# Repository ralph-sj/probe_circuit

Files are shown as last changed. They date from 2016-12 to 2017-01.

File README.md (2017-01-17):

# README
## RAS-J 12/01/2017

## Introduction
Here the design of a POF sensor is presented for the remote monitoring of a distillation column for use in undergraduate labs within Chemical Engineering.

## Hardware layout
The circuit is based around the LT1920 instrumentation amplifier which is used to amplify the signal from a photodiode with an incorporated trans-impedance amplifier.  

- Power input: this is supplied from a 12V supply connected to a 2.5mm jack on the front panel 
- LED power output: voltage for the LED's is connected to 2 banana plugs (red and black) on the front panel.
- Vsig output: this is the output signal and is connected by a BNC plug
- Vpd: the input from the photodiode.  This is at present connected via a 2.5mm audio jack but this can be replaced with a BNC connector

Resistors are used to set the levels for the offset voltage and the gain of the amplifier.  Switches are used to switch between variable resistors and fixed value resistors.  This is to enable the optimum level of both to be found and then set for future use.

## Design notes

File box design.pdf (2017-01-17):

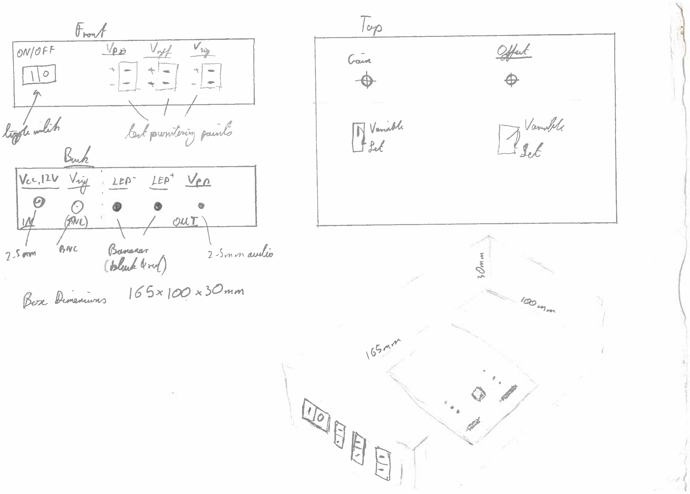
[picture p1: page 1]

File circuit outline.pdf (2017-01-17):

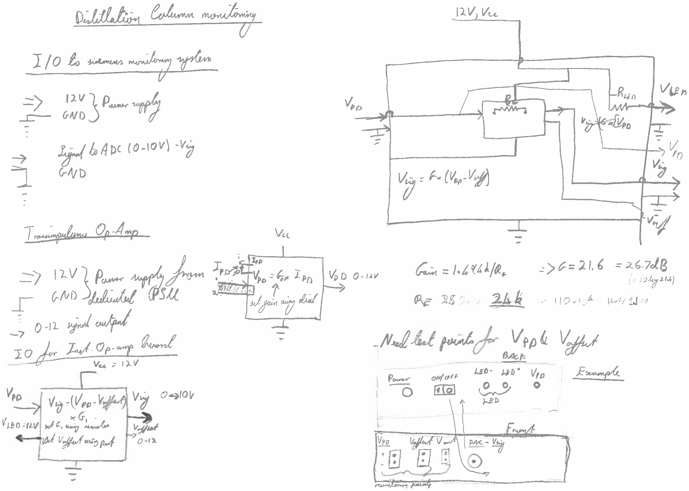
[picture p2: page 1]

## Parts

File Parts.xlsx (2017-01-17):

Distillation column BOM | RAS-J | 2016-10-28
Part | type | more info | size | purpose | No. required | Price | supplier link | Supplier order code | Mnfctr | Mnfctr. part no. | Net cost | Note
banana connector | plug | black | 4mm |  | 1 | £0.50 | farnel (http://uk.farnell.com/multicomp/24-247-2/receptacle-32a-4mm-panel-black/dp/1698951) | 1698951 | Multicomp | 24.247.2 | £0.50
banana connector | plug | red | 4mm |  | 1 | £0.50 | farnel (http://uk.farnell.com/multicomp/24-247-1/receptacle-32a-4mm-panel-red/dp/1698950) | 1698950 | Multicomp | 24.247.1 | £0.50
banana connector | jack | black | 4mm |  | 1 | £1.35 | farnel (http://uk.farnell.com/multicomp/25-413-2/plug-24a-4mm-cable-black/dp/1698964) | 1698964 | Multicomp | 25.413.2 | £1.35
banana connector | jack | red | 4mm |  | 1 | £1.35 | farnel (http://uk.farnell.com/multicomp/25-413-1/banana-plug-24a-4mm-cable-red/dp/1698963) | 1698963 | Multicomp | 25.413.1 | £1.35
DC power connector | plug | cable mount | 2.5mm |  | 1 | £0.50 | farnel (http://uk.farnell.com/multicomp/mp-122m/plug-dc-power-2-5mm/dp/1737249) | 1737249 | Multicomp | MP-122M | £0.50 | not needed if power supply used
DC power connector | jack | panel mount | 2.5mm |  | 1 | £0.90 | farnel (http://uk.farnell.com/multicomp/mj-15sr/chassis-socket-psu-panel-mount/dp/1737252) | 1737252 | Multicomp | MJ-15SR | £0.90
2-pole audio connector | plug | cable mount | 2.5mm |  | 1 | £0.73 | farnel (http://uk.farnell.com/lumberg/kls-2/connector-plug-3-5mm-mono-cable/dp/1243261) | 1243261 | Lumberg | KLS 2 | £0.73
2-pole audio connector | jack | panel mount | 2.5mm |  | 1 | £1.24 | farnel (http://uk.farnell.com/lumberg/kls-2/connector-plug-3-5mm-mono-cable/dp/1267394) | 1267394 | Pro Signal | MJ-164H | £1.24
DC power supply | mains AC adaptor | 12V, 10W output | 2.5mm jack |  | 1 | £7.50 | farnel (http://uk.farnell.com/multicomp/mcplg12v10wuk/plug-power-supply-10w-uk-12v/dp/1827445) | 1827445 | Multicomp | MCPLG12V10WUK | £7.50
On-off (rocker) switch | SPST | 250V, 16A max, illuminated |  |  | 1 | £1.16 | farnel (http://uk.farnell.com/multicomp/mc34231-091-72/rocker-switch-spst-red-i-o/dp/1454386) | 1454386 | Multicomp | MC34231-091-72 | £1.16
On-off (rocker) switch | SPST | 20A, non-illuminated, black/red |  |  | 1 | £0.64 | farnel (http://uk.farnell.com/multicomp/mc34224-071-1501/switch-spst-20a-250vac-blk-red/dp/1454382) | 1454382 | Multicomp | MC34224-071-1501 | £0.64
Potentiometer | Rotor | 10k, 200mW, +-20% |  | RG | 0 | £0.61 | farnel (http://uk.farnell.com/bi-technologies-tt-electronics/p160knp-0qc20b10k/pot-rotary-10k-20mm-20/dp/1760793) | 1760793 | BI Technologies | P160KNP-0QC20B10K | £0.00 | this or 249BBHS0XB25103KA
Potentiometer | Rotor | 10k, 1W, +-10% |  | RG | 1 | £6.94 | farnel (http://uk.farnell.com/vishay/249bbhs0xb25103ka/potentiometer-10k/dp/9609245?ost=249BBHS0XB25103KA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) | 9609245 | Vishay | 249BBHS0XB25103KA | £6.94 | this or P160KNP-0QC20B10K
BNC panel mount | jack | brass, <11GHz | 50 Ohm |  | 1 | £1.67 | farnel (http://uk.farnell.com/multicomp/13-25/rf-coaxial-bnc-straight-jack-50ohm/dp/1169699) | 1169699 | Multicomp | 13-25 | £1.67
Test point | thru-hole | for panel mounting | 1mm diameter |  | 1 | £1.41 | farnel (http://uk.farnell.com/multicomp/test-3/test-pin-pcb-1mm/dp/1702006) | 1702006 | Multicomp | TEST-3 | £1.41 | pack of 100, alt. to 1035
Test point | thru-hole | for panel mounting |  |  | 0 | £13.70 | farnel (http://uk.farnell.com/keystone/1035/test-point-pcb-through-hole/dp/2112492) | 2112492 | Keystone | 1035 | £0.00 | pack of 100, alt. to TEST-3
Potentiometer | thru-hole | 5k, 1W, +-10% |  | V_offset | 1 | £6.33 | farnel (http://uk.farnell.com/vishay/249bbhs0xb25502ka/potentiometer-5k/dp/9609237) | 9609237 | Vishay | 249BBHS0XB25502KA | £6.33
Switch | SPDT | panel mount, On-On | max 5A | RG_select | 1 | £1.40 | farnel (http://uk.farnell.com/multicomp/1ms1t1b5m1qe/switch-spdt-2-0a-250v/dp/9473378) | 9473378 | Multicomp | 1MS1T1B5M1QE | £1.40
Instrument Amplifier | SOIC, 1MHz | Offset: 30 uV, Vcc: 4.5 – 40V |  |  | 1 | 5.56 | farnel (http://uk.farnell.com/linear-technology/lt1920is8-pbf/instr-amplifier-1mhz-95db-8soic/dp/2294665) | 2294665 | Linear Technology | LT1920IS8#PBF | £5.56
 |  |  |  |  |  |  |  |  |  | TOTAL | 39.68

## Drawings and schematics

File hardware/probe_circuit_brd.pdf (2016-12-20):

J8 | J9

R3

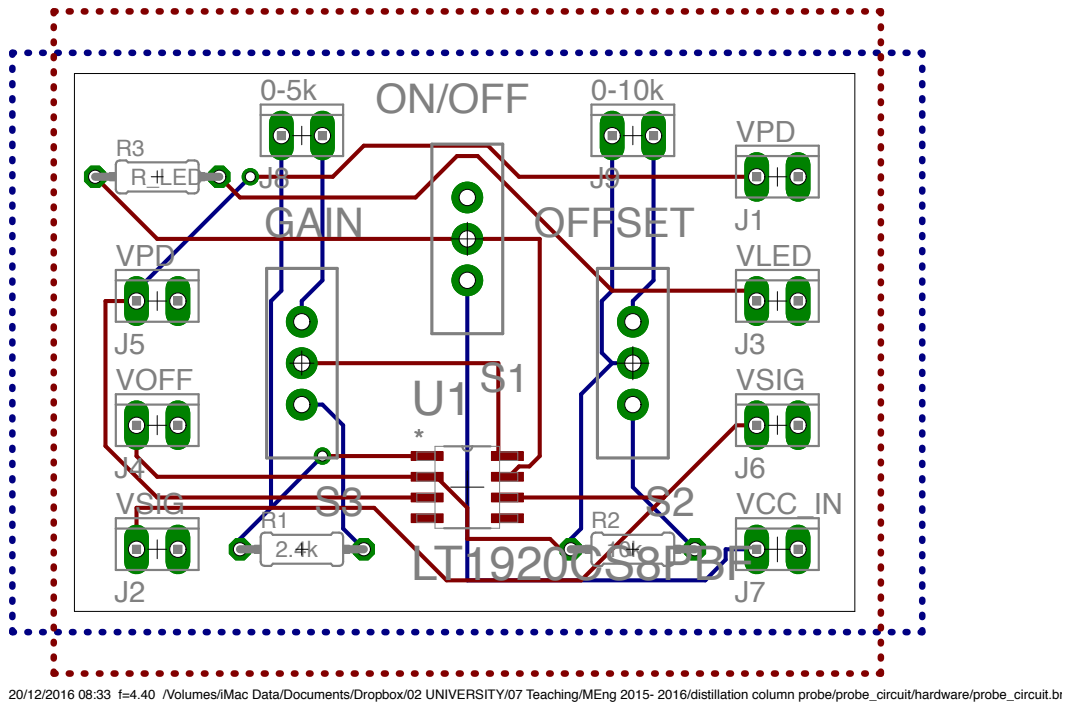
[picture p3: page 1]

20/12/2016 08:33 f=4.40 /Volumes/iMac Data/Documents/Dropbox/02 UNIVERSITY/07 Teaching/MEng 2015- 2016/distillation column probe/probe_circuit/hardware/probe_circuit.brd

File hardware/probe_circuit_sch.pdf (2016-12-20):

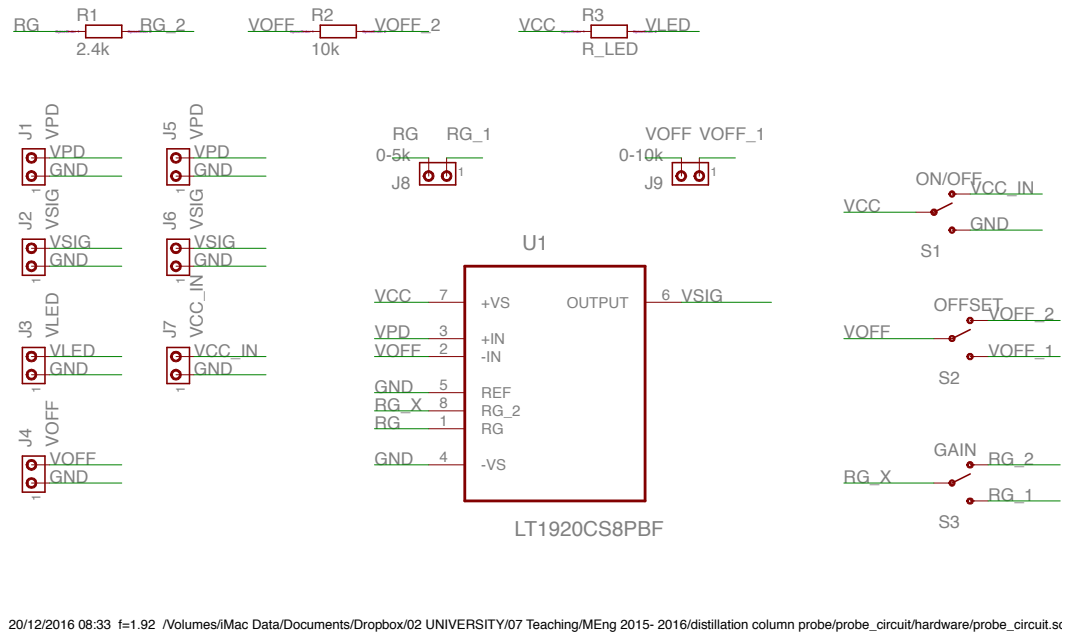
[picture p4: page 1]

VSIG VPD VLED VOFF

20/12/2016 08:33 f=1.92 /Volumes/iMac Data/Documents/Dropbox/02 UNIVERSITY/07 Teaching/MEng 2015- 2016/distillation column probe/probe_circuit/hardware/probe_circuit.sch (Sheet: 1/1)

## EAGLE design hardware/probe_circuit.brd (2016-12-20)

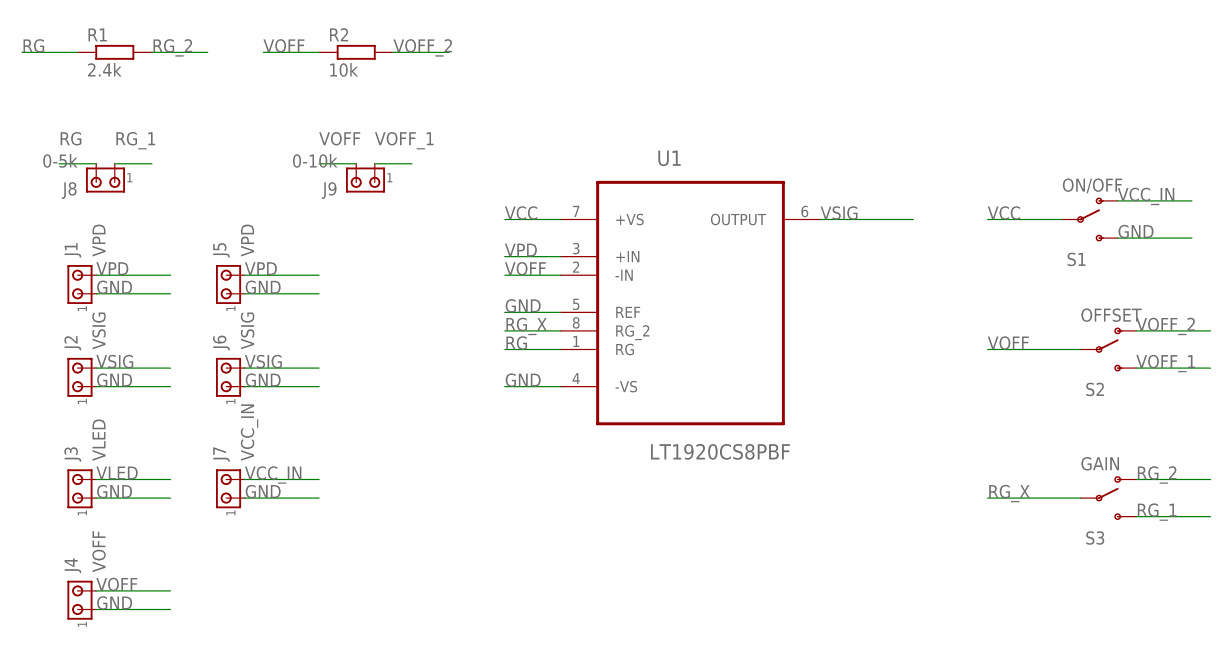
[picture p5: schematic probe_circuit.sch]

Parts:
J1, J5: VPD; 10X02MTA
J2, J6: VSIG; 10X02MTA
J3: VLED; 10X02MTA
J4: VOFF; 10X02MTA
J7: VCC_IN; 10X02MTA
J8: 0-5k; 10X02MTA
J9: 0-10k; 10X02MTA
R1: 2.4k; 0204/7
R2: 10k; 0204/7
S1: ON/OFF; SWITCH-SPDT
S2: OFFSET; SWITCH-SPDT
S3: GAIN; SWITCH-SPDT
U1: LT1920CS8PBF; SOIC127P600X175-8N

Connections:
GND: J1.1, J2.1, J3.1, J4.1, J5.1, J6.1, J7.1, S1.3 (S), U1.4 (-VS), U1.5 (REF)
RG: J8.2, R1.1, U1.1 (RG)
RG_1: J8.1, S3.3 (S)
RG_2: R1.2, S3.1 (O)
RG_X: S3.2, U1.8 (RG_2)
VCC: S1.2, U1.7 (+VS); also elsewhere on the board
VCC_IN: J7.2, S1.1 (O)
VLED: J3.2; also elsewhere on the board
VOFF: J4.2, J9.2, R2.1, S2.2, U1.2 (-IN)
VOFF_1: J9.1, S2.3 (S)
VOFF_2: R2.2, S2.1 (O)
VPD: J1.2, J5.2, U1.3 (+IN)
VSIG: J2.2, J6.2, U1.6 (OUTPUT)

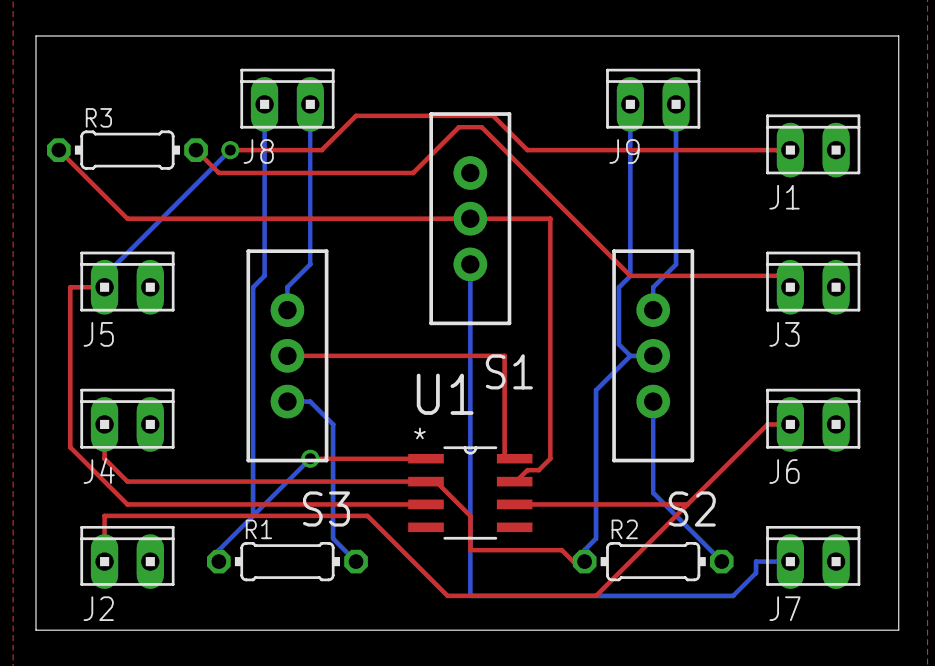
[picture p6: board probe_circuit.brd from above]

Board: 2 copper layers, 47.9 x 33.0 mm, 16 parts (0 on the bottom side), 13 nets.

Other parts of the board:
R3: R_LED; 0204/7

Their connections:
VCC: R3.1; also elsewhere on the board
VLED: R3.2; also elsewhere on the board

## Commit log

2016-10-27 Added schematic
    [probe_circuit.sch]
2016-10-27 Added components to board
    - added LT1920 and resistor to board
    - generated PCB
    [probe_circuit.brd, probe_circuit.sch]
2016-10-28 Parts spreadsheet added
    - plug parts (potential) logged to file
    [Parts.xlsx]
2016-10-28 update parts list
    - added audio plug/jack for signal connector
    [Parts.xlsx]
2016-10-31 - updated parts list
    [Parts.xlsx]
2016-10-31 added gain calculator
    [gain_calculator.xlsx]
2016-10-31 - updated PCB
    - added example switches, connector points and resistors to the board
    [probe_circuit.brd, probe_circuit.sch]
2016-10-31 update parts list
    [Parts.xlsx]
2016-12-19 AddedInst. Op. Amp. to parts
    [Parts.xlsx]
2016-12-19 Added connectors for variable resisotrs and conmpressed board.
    [probe_circuit.brd, probe_circuit.sch]
2016-12-19 updated board polygon areas and printed pdf view pf board
    [probe_circuit.brd]
2016-12-20 Connected VLED to VCC via resistor. Amended polygon area.
    [probe_circuit.brd]
2016-12-20 Printed brd and sch files to pdf
    [probe_circuit.sch]
2017-01-17 added circuit and physical outline sketches
2017-01-17 updated box design svg and parts list
    [Parts.xlsx]

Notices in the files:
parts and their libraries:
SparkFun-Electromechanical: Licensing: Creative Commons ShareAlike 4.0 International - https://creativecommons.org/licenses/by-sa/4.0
